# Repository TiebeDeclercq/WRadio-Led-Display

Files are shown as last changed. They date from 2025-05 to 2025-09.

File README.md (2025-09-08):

# WRadio LED Display
A custom-built LED display that showcases WRadio's logo with smooth animations and interactive brightness/animation controls via a built-in button.
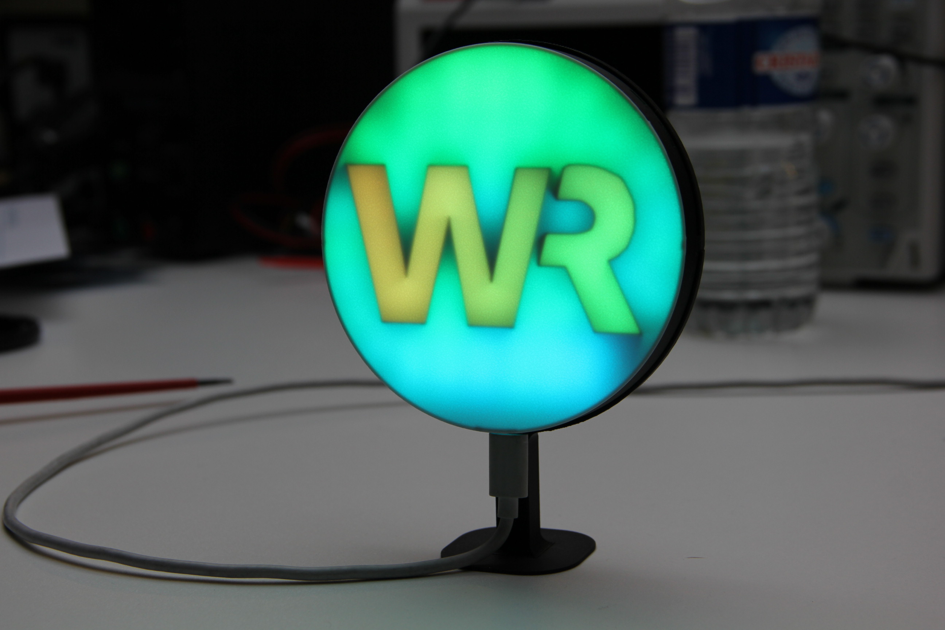
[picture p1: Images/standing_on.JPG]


## Hardware Overview
The design features a straightforward schematic controlled by an STM32F030F4P6TR microcontroller, providing reliable performance in a compact form factor and a cheap price.
Schematic

## Assembly Instructions
### PCB Assembly
For soldering, refer to the included BOM (Bill of Materials) file. All components are 0805 package size for easy assembly.
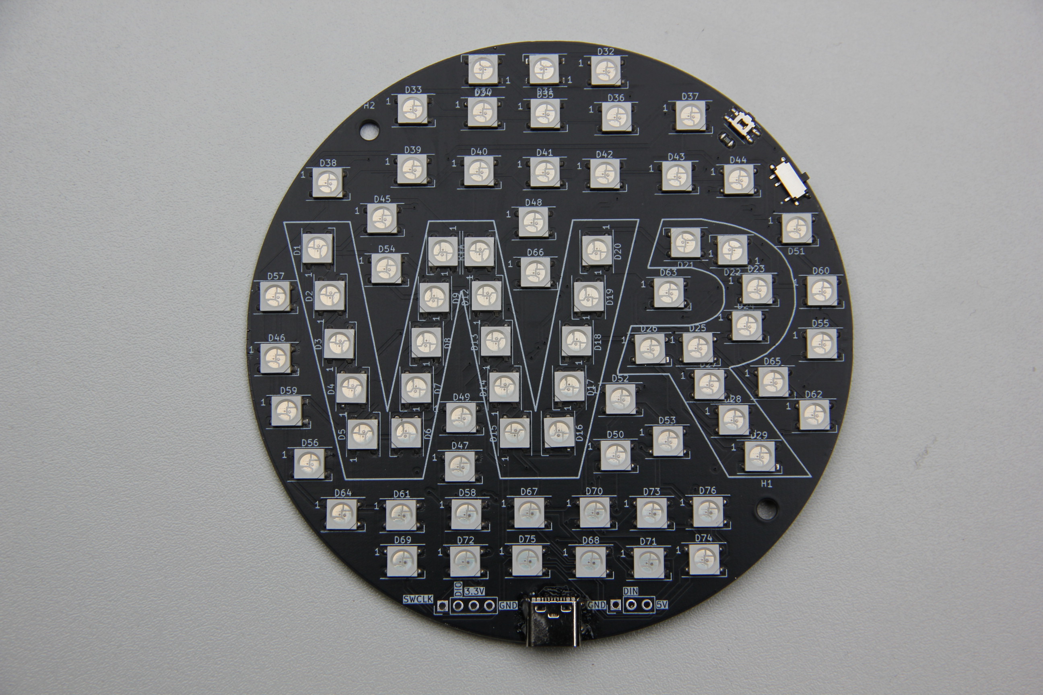
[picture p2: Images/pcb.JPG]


### 3D Printed Enclosure
The enclosure consists of two main parts:

**Top Piece:** Requires a multi-color 3D printer or filament switching capability. The first few layers must be printed in white filament to allow proper light diffusion through the logo.
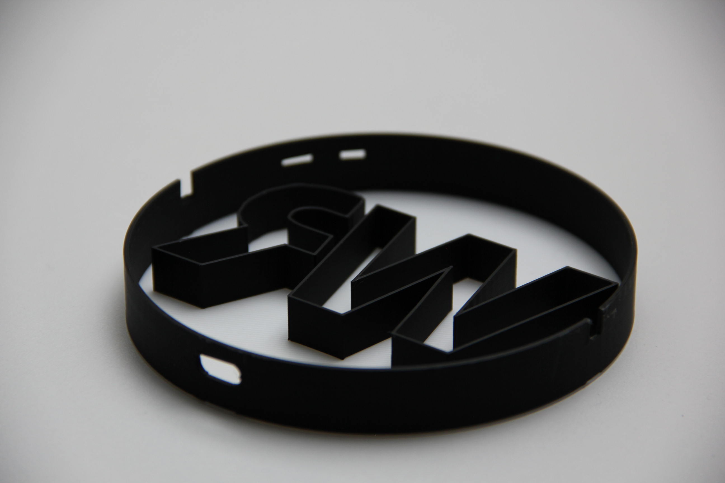
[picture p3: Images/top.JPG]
Top


**Bottom Piece:** Choose between the standard base or the angled standing version depending on your preferred display orientation.
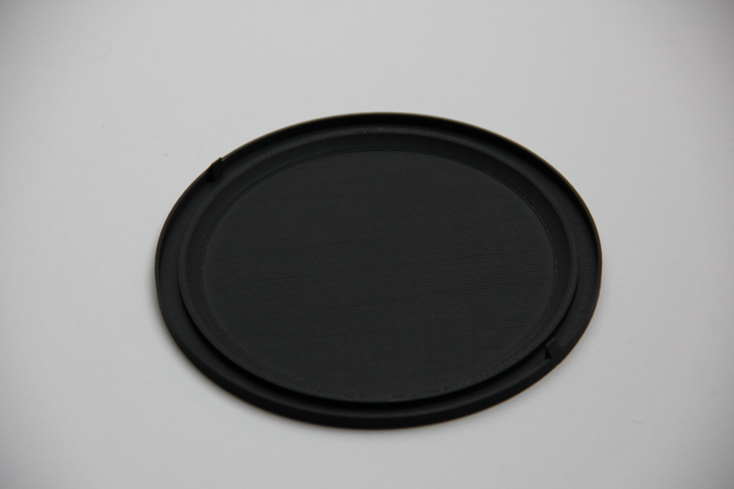
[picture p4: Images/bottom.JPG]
Bottom


### Final Assembly
To assemble the enclosure, simply click the top and bottom pieces together. Make sure the USB-C port on the PCB aligns properly with the corresponding hole in the 3D printed top piece for easy access to power and programming.

## Software
The firmware is developed using STM32CubeIDE and includes:
- Multiple animation modes
- Adjustable brightness levels
- Save system in flash memory
- Button-controlled user interface

## Getting Started
1. Assemble the PCB using the provided BOM
2. 3D print the enclosure parts
3. Insert the PCB into the top piece, ensuring USB-C port alignment
4. Click the top piece into place
5. Flash the firmware using STM32CubeIDE
6. Enjoy your custom WRadio LED display!

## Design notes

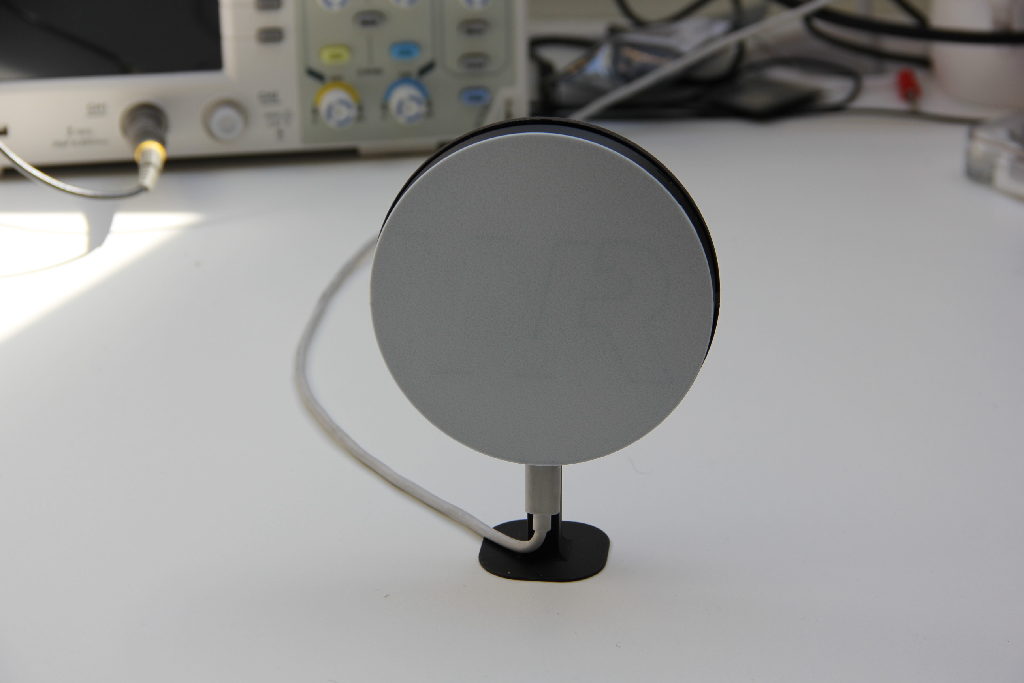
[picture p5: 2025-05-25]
Images/standing_off.JPG

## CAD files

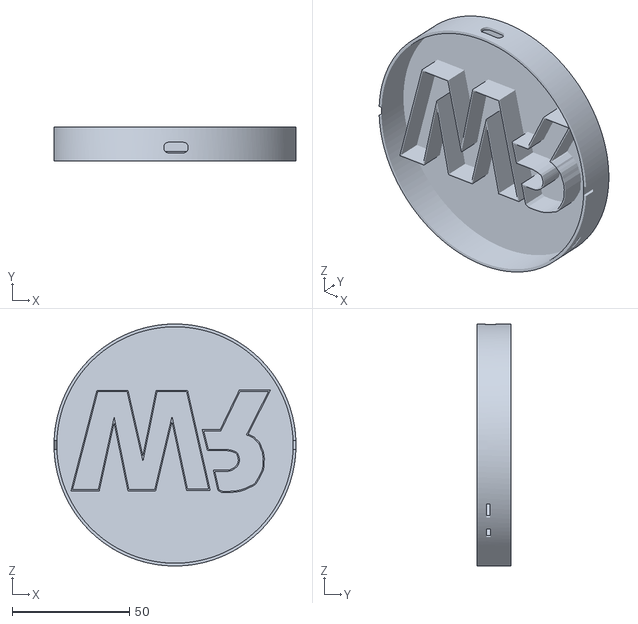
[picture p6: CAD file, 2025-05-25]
Stl's/Top.stl
103.0 x 14.5 x 103.0

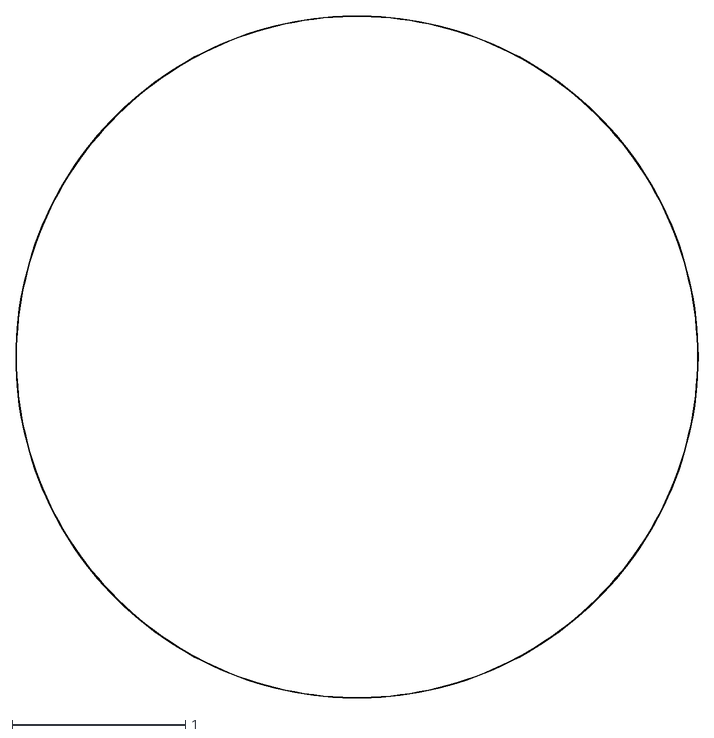
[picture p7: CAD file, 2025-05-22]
WRadioLogo/jlcPcbGerber/WRadioLogo-Edge_Cuts.dxf
3.94 x 3.94

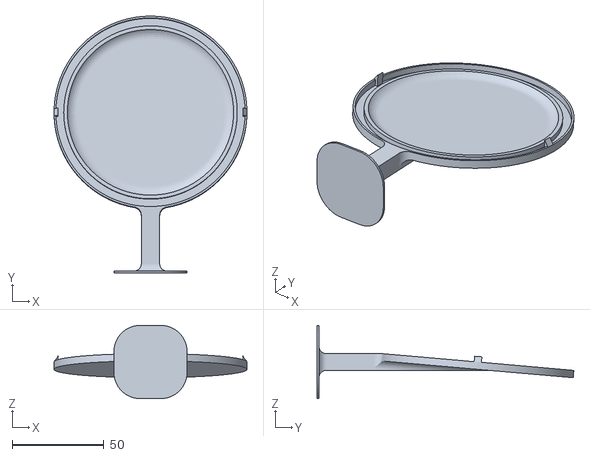
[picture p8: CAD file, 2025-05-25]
Stl's/Bottom_Standing.stl
105.2 x 139.9 x 40.0

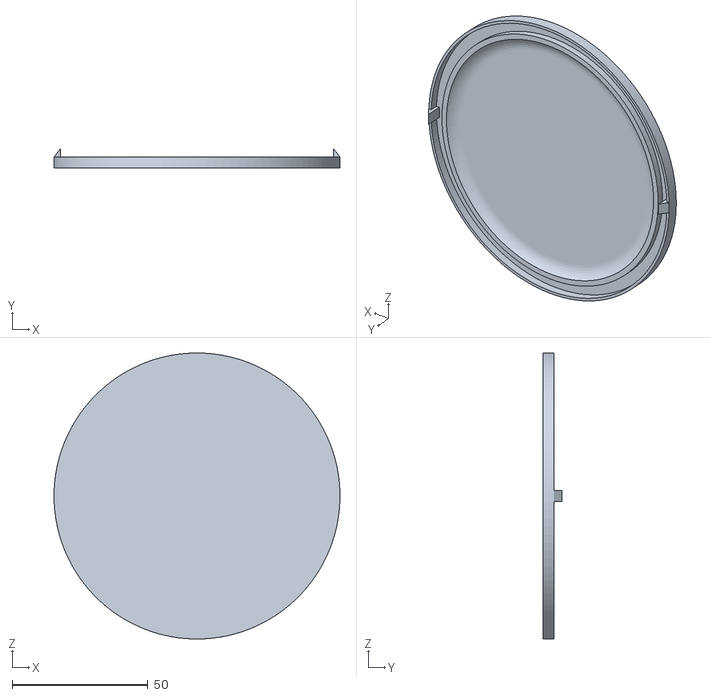
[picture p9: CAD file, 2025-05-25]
Stl's/Bottom_LayingDown.stl
105.2 x 7.00 x 105.2

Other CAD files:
WRadioLogo/jlcPcbGerber/WRadioLogo-F_Paste.dxf

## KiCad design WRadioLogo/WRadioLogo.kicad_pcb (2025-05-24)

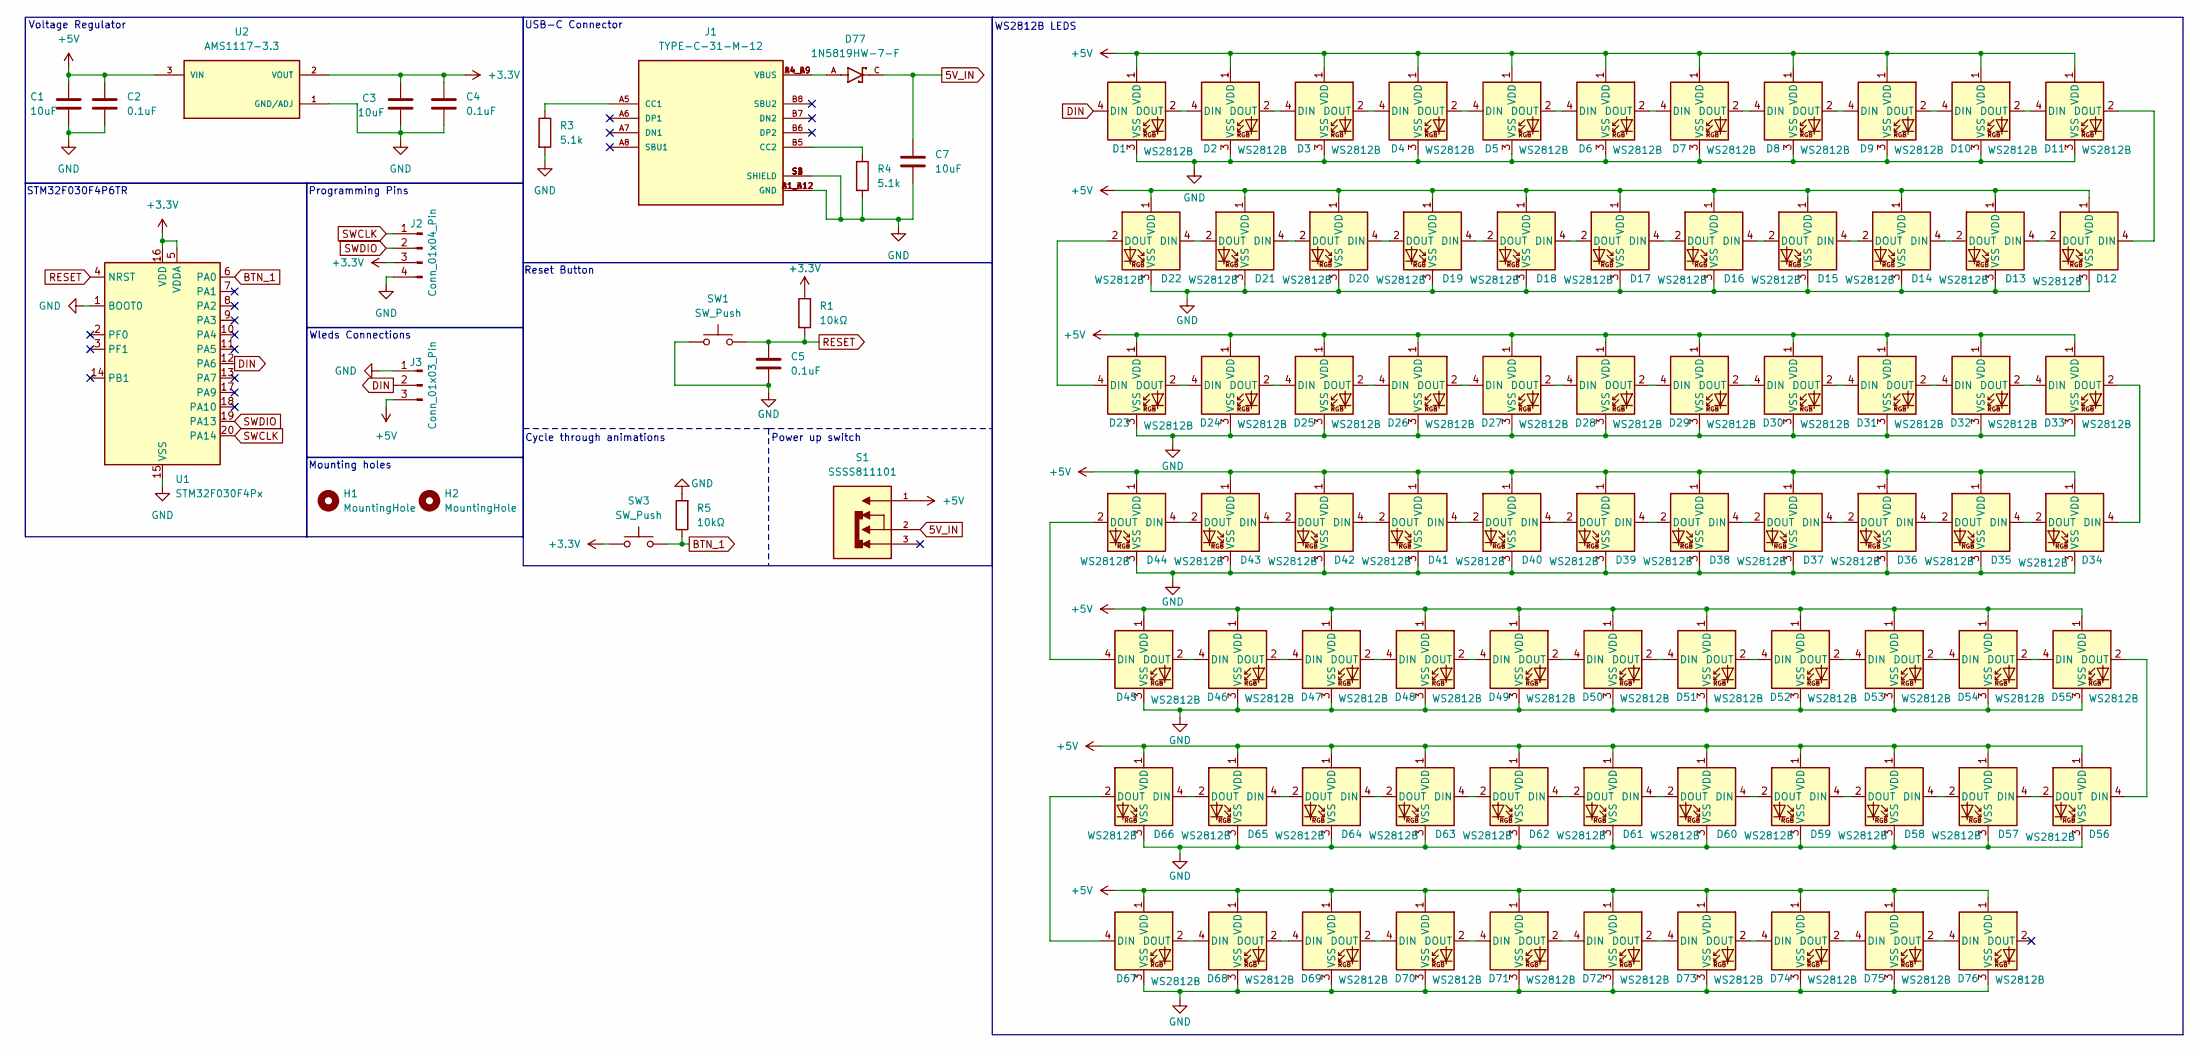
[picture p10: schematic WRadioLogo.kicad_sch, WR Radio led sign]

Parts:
C1, C3, C7: 10uF; C_0805_2012Metric_Pad1.18x1.45mm_HandSolder
C2, C4, C5: 0.1uF; C_0805_2012Metric_Pad1.18x1.45mm_HandSolder
D1, D2, D3, D4, D5, D6, D7, D8, D9, D10, D11, D12, D13, D14, D15, D16, D17, D18, D19, D20, D21, D22, D23, D24, D25, D26, D27, D28, D29, D30, D31, D32, D33, D34, D35, D36, D37, D38, D39, D40, D41, D42, D43, D44, D45, D46, D47, D48, D49, D50, D51, D52, D53, D54, D55, D56, D57, D58, D59, D60, D61, D62, D63, D64, D65, D66, D67, D68, D69, D70, D71, D72, D73, D74, D75, D76: WS2812B; LED_WS2812B_PLCC4_5.0x5.0mm_P3.2mm
D77: 1N5819HW-7-F; SOD3715X145N; PARTREV 18-2
H1, H2: MountingHole; MountingHole_3.2mm_M3
J1: TYPE-C-31-M-12; HRO_TYPE-C-31-M-12; PARTREV 2020.12.08
J2: Conn_01x04_Pin; PinHeader_1x04_P2.54mm_Vertical
J3: Conn_01x03_Pin; PinHeader_1x03_P2.54mm_Vertical
R1, R5: 10kΩ; R_0805_2012Metric_Pad1.20x1.40mm_HandSolder
R3, R4: 5.1k; R_0805_2012Metric_Pad1.20x1.40mm_HandSolder
S1: SSSS811101; SW_SSSS811101; PARTREV N/A
SW1: SW_Push; SW_SPST_FSMSM
SW3: SW_Push; Panasonic_EVQPUJ_EVQPUA
U1: STM32F030F4Px; TSSOP-20_4.4x6.5mm_P0.65mm
U2: AMS1117-3.3; SOT229P700X180-4N; PARTREV N/A

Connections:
5V_IN: C7.1, D77.C, S1.2
+3.3V: C3.1, C4.1, J2.3, R1.1, SW3.1, U1.5 (VDDA), U1.16 (VDD), U2.2 (VOUT)
+5V: C1.1, C2.1, D1.1 (VDD), D2.1 (VDD), D3.1 (VDD), D4.1 (VDD), D5.1 (VDD), D6.1 (VDD), D7.1 (VDD), D8.1 (VDD), D9.1 (VDD), D10.1 (VDD), D11.1 (VDD), D12.1 (VDD), D13.1 (VDD), D14.1 (VDD), D15.1 (VDD), D16.1 (VDD), D17.1 (VDD), D18.1 (VDD), D19.1 (VDD), D20.1 (VDD), D21.1 (VDD), D22.1 (VDD), D23.1 (VDD), D24.1 (VDD), D25.1 (VDD), D26.1 (VDD), D27.1 (VDD), D28.1 (VDD), D29.1 (VDD), D30.1 (VDD), D31.1 (VDD), D32.1 (VDD), D33.1 (VDD), D34.1 (VDD), D35.1 (VDD), D36.1 (VDD), D37.1 (VDD), D38.1 (VDD), D39.1 (VDD), D40.1 (VDD), D41.1 (VDD), D42.1 (VDD), D43.1 (VDD), D44.1 (VDD), D45.1 (VDD), D46.1 (VDD), D47.1 (VDD), D48.1 (VDD), D49.1 (VDD), D50.1 (VDD), D51.1 (VDD), D52.1 (VDD), D53.1 (VDD), D54.1 (VDD), D55.1 (VDD), D56.1 (VDD), D57.1 (VDD), D58.1 (VDD), D59.1 (VDD), D60.1 (VDD), D61.1 (VDD), D62.1 (VDD), D63.1 (VDD), D64.1 (VDD), D65.1 (VDD), D66.1 (VDD), D67.1 (VDD), D68.1 (VDD), D69.1 (VDD), D70.1 (VDD), D71.1 (VDD), D72.1 (VDD), D73.1 (VDD), D74.1 (VDD), D75.1 (VDD), D76.1 (VDD), J3.3, S1.1, U2.3 (VIN)
BTN_1: R5.1, SW3.2, U1.6 (PA0)
DIN: D1.4 (DIN), J3.2, U1.12 (PA6)
GND: C1.2, C2.2, C3.2, C4.2, C5.2, C7.2, D1.3 (VSS), D2.3 (VSS), D3.3 (VSS), D4.3 (VSS), D5.3 (VSS), D6.3 (VSS), D7.3 (VSS), D8.3 (VSS), D9.3 (VSS), D10.3 (VSS), D11.3 (VSS), D12.3 (VSS), D13.3 (VSS), D14.3 (VSS), D15.3 (VSS), D16.3 (VSS), D17.3 (VSS), D18.3 (VSS), D19.3 (VSS), D20.3 (VSS), D21.3 (VSS), D22.3 (VSS), D23.3 (VSS), D24.3 (VSS), D25.3 (VSS), D26.3 (VSS), D27.3 (VSS), D28.3 (VSS), D29.3 (VSS), D30.3 (VSS), D31.3 (VSS), D32.3 (VSS), D33.3 (VSS), D34.3 (VSS), D35.3 (VSS), D36.3 (VSS), D37.3 (VSS), D38.3 (VSS), D39.3 (VSS), D40.3 (VSS), D41.3 (VSS), D42.3 (VSS), D43.3 (VSS), D44.3 (VSS), D45.3 (VSS), D46.3 (VSS), D47.3 (VSS), D48.3 (VSS), D49.3 (VSS), D50.3 (VSS), D51.3 (VSS), D52.3 (VSS), D53.3 (VSS), D54.3 (VSS), D55.3 (VSS), D56.3 (VSS), D57.3 (VSS), D58.3 (VSS), D59.3 (VSS), D60.3 (VSS), D61.3 (VSS), D62.3 (VSS), D63.3 (VSS), D64.3 (VSS), D65.3 (VSS), D66.3 (VSS), D67.3 (VSS), D68.3 (VSS), D69.3 (VSS), D70.3 (VSS), D71.3 (VSS), D72.3 (VSS), D73.3 (VSS), D74.3 (VSS), D75.3 (VSS), D76.3 (VSS), J1.A1_B12 (GND), J1.B1_A12 (GND), J1.S1 (SHIELD), J1.S2 (SHIELD), J1.S3 (SHIELD), J1.S4 (SHIELD), J2.4, J3.1, R3.2, R4.2, R5.2, SW1.1, U1.1 (BOOT0), U1.15 (VSS), U2.1 (GND/ADJ)
unnamed: D1.2 (DOUT), D2.4 (DIN)
unnamed: D2.2 (DOUT), D3.4 (DIN)
unnamed: D3.2 (DOUT), D4.4 (DIN)
unnamed: D4.2 (DOUT), D5.4 (DIN)
unnamed: D5.2 (DOUT), D6.4 (DIN)
unnamed: D6.2 (DOUT), D7.4 (DIN)
unnamed: D7.2 (DOUT), D8.4 (DIN)
unnamed: D8.2 (DOUT), D9.4 (DIN)
unnamed: D9.2 (DOUT), D10.4 (DIN)
unnamed: D10.2 (DOUT), D11.4 (DIN)
unnamed: D11.2 (DOUT), D12.4 (DIN)
unnamed: D12.2 (DOUT), D13.4 (DIN)
unnamed: D13.2 (DOUT), D14.4 (DIN)
unnamed: D14.2 (DOUT), D15.4 (DIN)
unnamed: D15.2 (DOUT), D16.4 (DIN)
unnamed: D16.2 (DOUT), D17.4 (DIN)
unnamed: D17.2 (DOUT), D18.4 (DIN)
unnamed: D18.2 (DOUT), D19.4 (DIN)
unnamed: D19.2 (DOUT), D20.4 (DIN)
unnamed: D20.2 (DOUT), D21.4 (DIN)
unnamed: D21.2 (DOUT), D22.4 (DIN)
unnamed: D22.2 (DOUT), D23.4 (DIN)
unnamed: D23.2 (DOUT), D24.4 (DIN)
unnamed: D24.2 (DOUT), D25.4 (DIN)
unnamed: D25.2 (DOUT), D26.4 (DIN)
unnamed: D26.2 (DOUT), D27.4 (DIN)
unnamed: D27.2 (DOUT), D28.4 (DIN)
unnamed: D28.2 (DOUT), D29.4 (DIN)
unnamed: D29.2 (DOUT), D30.4 (DIN)
unnamed: D30.2 (DOUT), D31.4 (DIN)
unnamed: D31.2 (DOUT), D32.4 (DIN)
unnamed: D32.2 (DOUT), D33.4 (DIN)
unnamed: D33.2 (DOUT), D34.4 (DIN)
unnamed: D34.2 (DOUT), D35.4 (DIN)
unnamed: D35.2 (DOUT), D36.4 (DIN)
unnamed: D36.2 (DOUT), D37.4 (DIN)
unnamed: D37.2 (DOUT), D38.4 (DIN)
unnamed: D38.2 (DOUT), D39.4 (DIN)
unnamed: D39.2 (DOUT), D40.4 (DIN)
unnamed: D40.2 (DOUT), D41.4 (DIN)
unnamed: D41.2 (DOUT), D42.4 (DIN)
unnamed: D42.2 (DOUT), D43.4 (DIN)
unnamed: D43.2 (DOUT), D44.4 (DIN)
unnamed: D44.2 (DOUT), D45.4 (DIN)
unnamed: D45.2 (DOUT), D46.4 (DIN)
unnamed: D46.2 (DOUT), D47.4 (DIN)
unnamed: D47.2 (DOUT), D48.4 (DIN)
unnamed: D48.2 (DOUT), D49.4 (DIN)
unnamed: D49.2 (DOUT), D50.4 (DIN)
unnamed: D50.2 (DOUT), D51.4 (DIN)
unnamed: D51.2 (DOUT), D52.4 (DIN)
unnamed: D52.2 (DOUT), D53.4 (DIN)
unnamed: D53.2 (DOUT), D54.4 (DIN)
unnamed: D54.2 (DOUT), D55.4 (DIN)
unnamed: D55.2 (DOUT), D56.4 (DIN)
unnamed: D56.2 (DOUT), D57.4 (DIN)
unnamed: D57.2 (DOUT), D58.4 (DIN)
unnamed: D58.2 (DOUT), D59.4 (DIN)
unnamed: D59.2 (DOUT), D60.4 (DIN)
unnamed: D60.2 (DOUT), D61.4 (DIN)
unnamed: D61.2 (DOUT), D62.4 (DIN)
unnamed: D62.2 (DOUT), D63.4 (DIN)
unnamed: D63.2 (DOUT), D64.4 (DIN)
unnamed: D64.2 (DOUT), D65.4 (DIN)
unnamed: D65.2 (DOUT), D66.4 (DIN)
unnamed: D66.2 (DOUT), D67.4 (DIN)
unnamed: D67.2 (DOUT), D68.4 (DIN)
unnamed: D68.2 (DOUT), D69.4 (DIN)
unnamed: D69.2 (DOUT), D70.4 (DIN)
unnamed: D70.2 (DOUT), D71.4 (DIN)
unnamed: D71.2 (DOUT), D72.4 (DIN)
unnamed: D72.2 (DOUT), D73.4 (DIN)
unnamed: D73.2 (DOUT), D74.4 (DIN)
unnamed: D74.2 (DOUT), D75.4 (DIN)
unnamed: D75.2 (DOUT), D76.4 (DIN)
unnamed: D77.A, J1.A4_B9 (VBUS), J1.B4_A9 (VBUS)
unnamed: J1.A5 (CC1), R3.1
unnamed: J1.B5 (CC2), R4.1
RESET: C5.1, R1.2, SW1.2, U1.4 (NRST)
SWCLK: J2.1, U1.20 (PA14)
SWDIO: J2.2, U1.19 (PA13)

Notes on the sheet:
Voltage Regulator
Wleds Connections
Programming Pins
USB-C Connector
Reset Button
Cycle through animations
Power up switch
WS2812B LEDS
Mounting holes
STM32F030F4P6TR

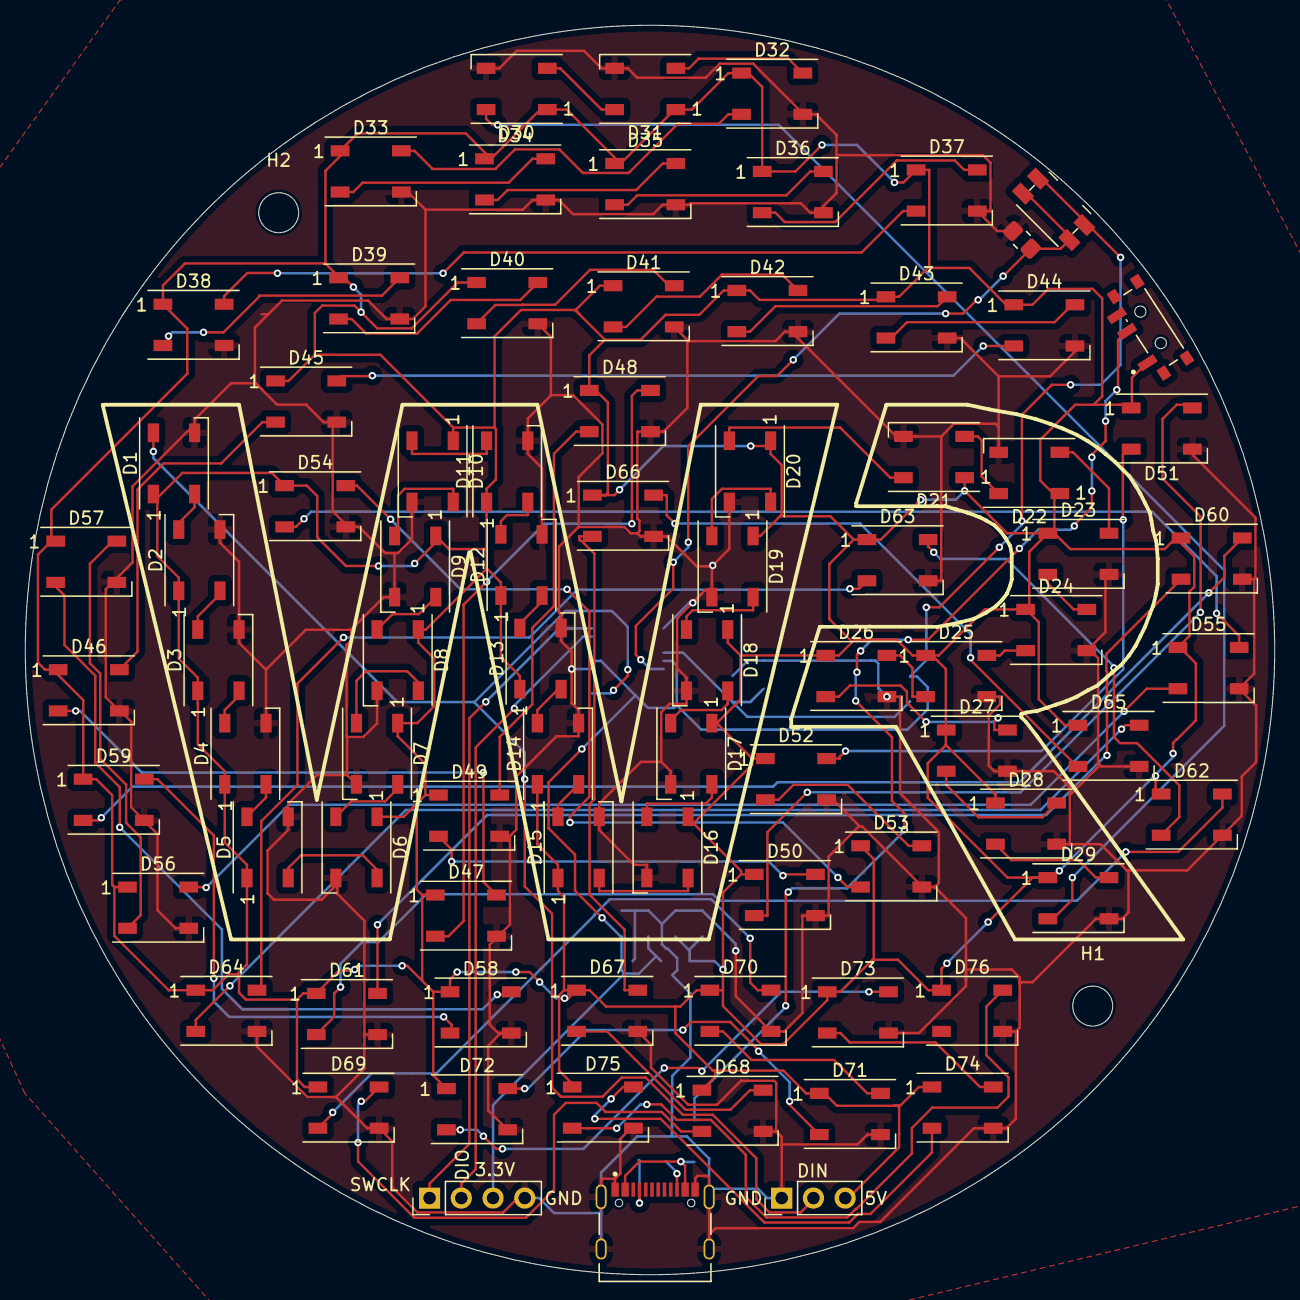
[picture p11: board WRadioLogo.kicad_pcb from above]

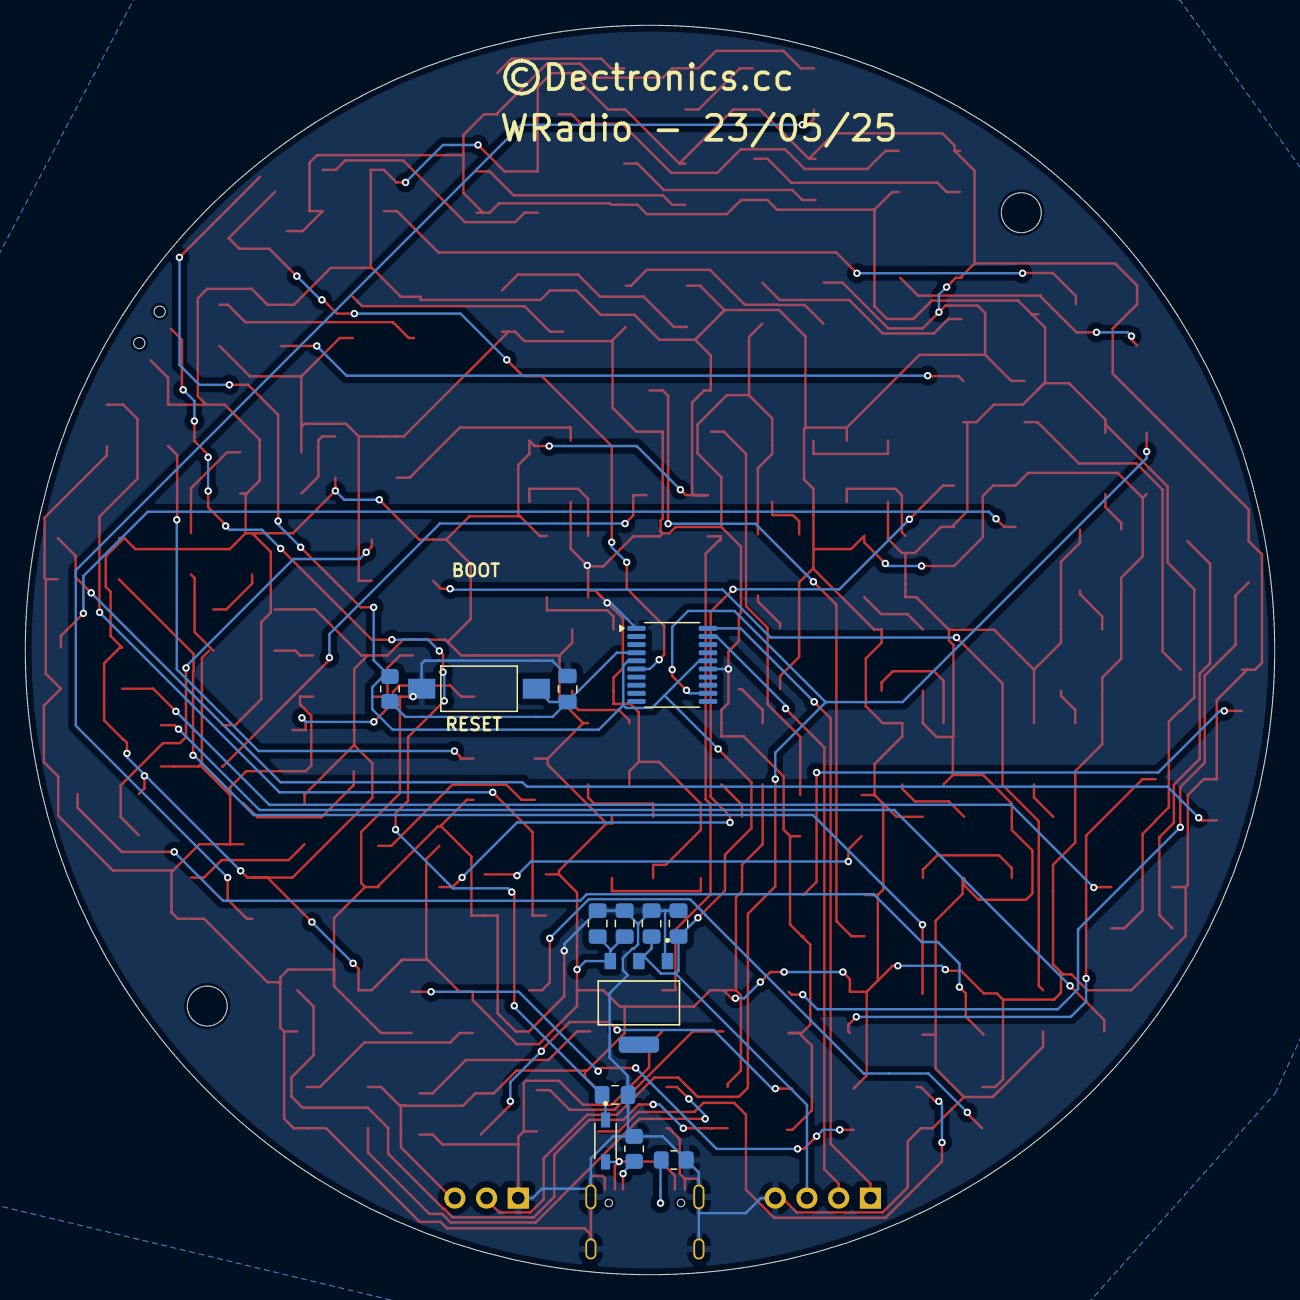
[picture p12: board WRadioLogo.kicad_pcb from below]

Board: 2 copper layers, 100.0 x 100.0 mm, 97 parts (13 on the bottom side), 87 nets.

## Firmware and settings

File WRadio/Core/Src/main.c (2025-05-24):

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
/* Includes ------------------------------------------------------------------*/
#include "main.h"

/* USER CODE BEGIN Includes */
#include "ws2812b.h"
#include "flash_storage.h"
/* USER CODE END Includes */

/* USER CODE BEGIN PD */
#define SAVE_DELAY_MS    		2000    // Wait 2 seconds before saving to flash
#define LONG_PRESS_TIME_MS      1000    // 1 second for long press detection
#define BRIGHTNESS_LEVELS       5       // Number of brightness levels
/* USER CODE END PD */

TIM_HandleTypeDef htim3;
DMA_HandleTypeDef hdma_tim3_ch1_trig;

/* USER CODE BEGIN PV */
/* Global variables */
static effect_mode_t currentMode = MODE_STATIC_LOGO;
static uint32_t lastButtonPress = 0;
static uint32_t lastModeChange = 0;
static uint32_t buttonPressStartTime = 0;
static uint8_t buttonPressed = 0;
static uint8_t buttonReleased = 1;
static uint8_t modePendingSave = 0;
static uint8_t brightnessLevel = 2;

static uint8_t brightnessLevels[BRIGHTNESS_LEVELS] = {50, 100, 150, 200, 255};
/*
Level 0: [████░░░░░░] 50   (20% brightness)
Level 1: [████████░░] 100  (40% brightness)  ◀── Default
Level 2: [██████████] 150  (60% brightness)
Level 3: [██████████] 200  (80% brightness)
Level 4: [██████████] 255  (100% brightness)
*/

uint8_t baseBrightness = 100;  // This will be set based on brightness level
/* USER CODE END PV */

void SystemClock_Config(void);
static void MX_GPIO_Init(void);
static void MX_DMA_Init(void);
static void MX_TIM3_Init(void);
/* USER CODE BEGIN PFP */
void HandleButtonPress(void);
void HandleFlashSave(void);
/* USER CODE END PFP */

/**
  * @brief  The application entry point.
  * @retval int
  */
int main(void)
{

  /* MCU Configuration--------------------------------------------------------*/

  /* Reset of all peripherals, Initializes the Flash interface and the Systick. */
  HAL_Init();

  /* Configure the system clock */
  SystemClock_Config();

  /* Initialize all configured peripherals */
  MX_GPIO_Init();
  MX_DMA_Init();
  MX_TIM3_Init();
  /* USER CODE BEGIN 2 */

  HAL_Delay(100);

  // Initialize flash storage
  Flash_Storage_Init();

  // Load saved effect mode and brightness
  currentMode = Flash_Storage_ReadMode();
  brightnessLevel = Flash_Storage_ReadBrightnessLevel();

  // Set the base brightness from the level
  baseBrightness = brightnessLevels[brightnessLevel];
  globalBrightness = baseBrightness;

  // Initialize the WS2812B driver
  WS2812B_Init();

  // Apply the loaded effect immediately
  WS2812B_RunEffect(currentMode);

  /* USER CODE END 2 */

  /* Infinite loop */
  /* USER CODE BEGIN WHILE */
  while (1)
  {
    /* USER CODE END WHILE */

    /* USER CODE BEGIN 3 */
    HandleButtonPress();
    HandleFlashSave();      // Check if we need to save settings
    WS2812B_RunEffect(currentMode);
    HAL_Delay(1);

  }
  /* USER CODE END 3 */
}

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
/* USER CODE BEGIN 4 */

void HandleButtonPress(void)
{
    uint8_t buttonState = HAL_GPIO_ReadPin(GPIOA, GPIO_PIN_0);
    uint32_t currentTime = HAL_GetTick();

    if (buttonState == GPIO_PIN_SET && buttonReleased) {
        // Button just pressed down
        if (currentTime - lastButtonPress > 50) { // 50ms debounce
            buttonPressed = 1;
            buttonReleased = 0;
            buttonPressStartTime = currentTime;
            lastButtonPress = currentTime;
        }
    }
    else if (buttonState == GPIO_PIN_RESET && !buttonReleased) {
        // Button just released
        buttonReleased = 1;
        buttonPressed = 0;

        uint32_t pressDuration = currentTime - buttonPressStartTime;

        if (pressDuration >= LONG_PRESS_TIME_MS) {
            // LONG PRESS - Change brightness
            brightnessLevel++;
            if (brightnessLevel >= BRIGHTNESS_LEVELS) {
                brightnessLevel = 0;  // Loop back to lowest
            }

            // Update base brightness that will be used by all effects
            baseBrightness = brightnessLevels[brightnessLevel];
            globalBrightness = baseBrightness;

            // Trigger static logo update if we're in static mode
            if (currentMode == MODE_STATIC_LOGO) {
                WS2812B_TriggerStaticLogoUpdate();
            }

            // Mark settings for saving
            modePendingSave = 1;
            lastModeChange = currentTime;

        } else if (pressDuration >= 200) {
            // SHORT PRESS - Change effect (with minimum 200ms press)
            currentMode++;
            if (currentMode >= MODE_COUNT) {
                currentMode = MODE_STATIC_LOGO;
            }

            // Mark mode for saving
            modePendingSave = 1;
            lastModeChange = currentTime;
        }
    }
}

void HandleFlashSave(void)
{
    /* Save to flash after SAVE_DELAY_MS milliseconds of no changes */
    if (modePendingSave) {
        uint32_t currentTime = HAL_GetTick();
        if (currentTime - lastModeChange > SAVE_DELAY_MS) {
            // Save the current mode and brightness level to flash
            if (Flash_Storage_SaveSettings(currentMode, brightnessLevel) == HAL_OK) {
                modePendingSave = 0;  // Clear the pending save flag
            }
        }
    }
}

// Add this function to main.c
void HAL_TIM_PWM_PulseFinishedCallback(TIM_HandleTypeDef *htim)
{
  if (htim->Instance == TIM3) {
    WS2812B_TIM_DMADelayPulseFinished();
  }
}
/* USER CODE END 4 */
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


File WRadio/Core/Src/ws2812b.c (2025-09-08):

/**
******************************************************************************
* @file           : ws2812b.c
* @brief          : handles ws2812b led animations of the matrix
******************************************************************************
*
* ██████╗ ███████╗ ██████╗████████╗██████╗  ██████╗ ███╗   ██╗██╗ ██████╗███████╗
* ██╔══██╗██╔════╝██╔════╝╚══██╔══╝██╔══██╗██╔═══██╗████╗  ██║██║██╔════╝██╔════╝
* ██║  ██║█████╗  ██║        ██║   ██████╔╝██║   ██║██╔██╗ ██║██║██║     ███████╗
* ██║  ██║██╔══╝  ██║        ██║   ██╔══██╗██║   ██║██║╚██╗██║██║██║     ╚════██║
* ██████╔╝███████╗╚██████╗   ██║   ██║  ██║╚██████╔╝██║ ╚████║██║╚██████╗███████║
* ╚═════╝ ╚══════╝ ╚═════╝   ╚═╝   ╚═╝  ╚═╝ ╚═════╝ ╚═╝  ╚═══╝╚═╝ ╚═════╝╚══════╝
*
******************************************************************************
* @author         : Tiebe Declercq
* @copyright      : Copyright (c) 2025 DECTRONICS. All rights reserved.
* @version        : 1.0.0
* @date           : 2025-05-24
******************************************************************************
*/
#include "ws2812b.h"
#include "main.h"
#include <string.h>
#include <stdbool.h>

#define WS2812B_ONE_PULSE   38
#define WS2812B_ZERO_PULSE  19
#define BASE_BRIGHTNESS     100

uint8_t ledBuffer[WS2812B_BUFFER_SIZE];
uint32_t currentColors[LED_COUNT];
volatile bool transferComplete = false;
uint8_t globalBrightness = BASE_BRIGHTNESS;
extern uint8_t baseBrightness;

#define W_START 0
#define W_END 20
#define R_START 20
#define R_END 28

extern TIM_HandleTypeDef htim3;
extern DMA_HandleTypeDef hdma_tim3_ch1_trig;

static uint8_t staticLogoNeedsUpdate = 1;

void WS2812B_Init(void)
{
    memset(currentColors, 0, sizeof(currentColors));
    globalBrightness = baseBrightness;
    WS2812B_SetLogoColors();
}

uint32_t WS2812B_Color(uint8_t r, uint8_t g, uint8_t b)
{
    r = (r * globalBrightness) / 255;
    g = (g * globalBrightness) / 255;
    b = (b * globalBrightness) / 255;
    return ((uint32_t)r << 16) | ((uint32_t)g << 8) | b;
}

void WS2812B_PrepareBuffer(void)
{
    uint16_t bufferIndex = 0;

    for (uint16_t i = 0; i < LED_COUNT; i++) {
        uint32_t color = currentColors[i];
        uint8_t green = (color >> 8) & 0xFF;
        uint8_t red = (color >> 16) & 0xFF;
        uint8_t blue = color & 0xFF;

        for (int8_t bit = 7; bit >= 0; bit--) {
            ledBuffer[bufferIndex++] = (green & (1 << bit)) ? WS2812B_ONE_PULSE : WS2812B_ZERO_PULSE;
        }
        for (int8_t bit = 7; bit >= 0; bit--) {
            ledBuffer[bufferIndex++] = (red & (1 << bit)) ? WS2812B_ONE_PULSE : WS2812B_ZERO_PULSE;
        }
        for (int8_t bit = 7; bit >= 0; bit--) {
            ledBuffer[bufferIndex++] = (blue & (1 << bit)) ? WS2812B_ONE_PULSE : WS2812B_ZERO_PULSE;
        }
    }

    for (uint16_t i = 0; i < WS2812B_RESET_LEN; i++) {
        ledBuffer[bufferIndex++] = 0;
    }
}

void WS2812B_SendToLEDs(void)
{
    transferComplete = false;
    HAL_TIM_PWM_Stop_DMA(&htim3, TIM_CHANNEL_1);

    WS2812B_PrepareBuffer();

    // Cast uint8_t buffer to uint32_t for DMA (DMA expects uint32_t pointer)
    if (HAL_TIM_PWM_Start_DMA(&htim3, TIM_CHANNEL_1, (uint32_t*)ledBuffer, WS2812B_BUFFER_SIZE) != HAL_OK) {
        return;
    }

    uint32_t timeout = HAL_GetTick() + 100;
    while (!transferComplete && HAL_GetTick() < timeout) {
    }
}

void WS2812B_TIM_DMADelayPulseFinished(void)
{
    transferComplete = true;
}

void WS2812B_SetLogoColors(void)
{
    /* W = Magenta */
    for(int i = W_START; i <= W_END; i++) {
        currentColors[i] = WS2812B_Color(255, 0, 100);
    }

    /* R = White */
    for(int i = R_START; i <= R_END; i++) {
        currentColors[i] = WS2812B_Color(255, 255, 255);
    }

    /* Background = DARK BLUE */
    for(int i = R_END + 1; i < LED_COUNT; i++) {
        currentColors[i] = WS2812B_Color(30, 30, 150);
    }

    WS2812B_SendToLEDs();
}

void WS2812B_Clear(void)
{
    memset(currentColors, 0, sizeof(currentColors));
    WS2812B_SendToLEDs();
}

void WS2812B_StaticLogoEffect(void)
{
    // Only update if needed (when switching to static mode or brightness changed)
    if (staticLogoNeedsUpdate) {
        globalBrightness = baseBrightness;  // Set brightness for static logo
        WS2812B_SetLogoColors();
        staticLogoNeedsUpdate = 0;  // Clear the update flag
    }
}

void WS2812B_BreatheEffect(void)
{
    static uint32_t lastUpdate = 0;
    static uint8_t breathDir = 1;
    static uint8_t breathBrightness = 50;  // Start at 50% of base

    if (HAL_GetTick() - lastUpdate < 30) return;
    lastUpdate = HAL_GetTick();

    if (breathDir) {
        breathBrightness++;
        if (breathBrightness >= 200) breathDir = 0;  // Max 200% of base
    } else {
        breathBrightness--;
        if (breathBrightness <= 50) breathDir = 1;   // Min 50% of base
    }

    // Calculate brightness as percentage of base brightness
    globalBrightness = (baseBrightness * breathBrightness) / 100;
    WS2812B_SetLogoColors();
}

void WS2812B_SparkleEffect(void)
{
    static uint32_t lastSparkle = 0;
    static uint16_t sparklePixel = 0;
    static uint8_t sparkleState = 0;

    if (HAL_GetTick() - lastSparkle < 150) return;
    lastSparkle = HAL_GetTick();

    globalBrightness = baseBrightness;

    if (sparkleState == 0) {
        WS2812B_SetLogoColors();
        sparklePixel = W_START + ws_random_byte(W_END - W_START + 1);
        currentColors[sparklePixel] = WS2812B_Color(255, 255, 255);
        sparkleState = 1;
    } else {
        WS2812B_SetLogoColors();
        sparkleState = 0;
    }

    WS2812B_SendToLEDs();
}

void WS2812B_WaveEffect(void)
{
    static uint32_t lastUpdate = 0;
    static uint16_t wavePos = W_START;
    static uint8_t waveSection = 0;

    if (HAL_GetTick() - lastUpdate < 80) return;
    lastUpdate = HAL_GetTick();

    globalBrightness = baseBrightness;
    WS2812B_SetLogoColors();

    if (waveSection == 0) {
        currentColors[wavePos] = WS2812B_Color(255, 150, 200);
        wavePos++;
        if (wavePos > W_END) {
            wavePos = R_START;
            waveSection = 1;
        }
    } else {
        currentColors[wavePos] = WS2812B_Color(255, 0, 100);
        wavePos++;
        if (wavePos > R_END) {
            wavePos = W_START;
            waveSection = 0;
        }
    }

    WS2812B_SendToLEDs();
}

void WS2812B_PulseEffect(void)
{
    static uint32_t lastPulse = 0;
    static uint8_t pulseState = 0;

    if (HAL_GetTick() - lastPulse < 400) return;
    lastPulse = HAL_GetTick();

    if (pulseState == 0) {
        globalBrightness = baseBrightness * 2;  // 200% of base brightness
        if (globalBrightness > 255) globalBrightness = 255;  // Cap at max
        WS2812B_SetLogoColors();
        pulseState = 1;
    } else {
        globalBrightness = baseBrightness;  // Back to base brightness
        WS2812B_SetLogoColors();
        pulseState = 0;
    }
}
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

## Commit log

2025-05-22 V1 PCB
2025-05-24 nieuwe patronen + helderheid wip
    [WRadioLogo.kicad_pcb, WRadioLogo.kicad_sch]

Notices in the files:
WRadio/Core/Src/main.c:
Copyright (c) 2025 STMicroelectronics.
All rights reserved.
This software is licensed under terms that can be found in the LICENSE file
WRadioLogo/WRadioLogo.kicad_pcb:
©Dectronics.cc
